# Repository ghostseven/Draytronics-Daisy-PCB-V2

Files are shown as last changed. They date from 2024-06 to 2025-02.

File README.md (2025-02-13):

# Draytronics-Daisy-PCB-V2

daisy  

An open source macro pad with a rotary encoder and OLED panel, this is an alternative version to the original through hole Daisy kit. More info / PCB designs available at [draytronics.co.uk/daisyV2](https://www.draytronics.co.uk/daisyv2/)

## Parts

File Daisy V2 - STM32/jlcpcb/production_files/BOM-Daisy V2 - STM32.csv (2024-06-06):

Comment | Designator | Footprint | LCSC
SN74LV1T34DBV | U5 | SOT-23-5 | C100024
5.1k | R1,R2,R3,R4,R5,R6 | R_0402_1005Metric | C105872
500mA | F1 | Fuse_1206_3216Metric | C135341
10uF | C2 | C_0603_1608Metric | C19702
PRTR5V0U2X | U2 | SOT-143 | C2827688
SW_SPST | BOOT1,RST1 | SW_SPST_TL3342 | C2886897
USB_C_Receptacle_USB2.0 | J1 | USB_C_Receptacle_HRO_TYPE-C-31-M-12 | C2988369
100nF | C1,C3,C4,C5,C6,C7,C8 | C_0402_1005Metric | C307331
1uF | C10,C9 | C_0402_1005Metric | C52923
XC6206PxxxMR-Regulator_Linear | U3 | SOT-23 | C5446
D_Small | D1,D2,D3,D4,D5,D6,D7,D8,D9 | D_SOD-123 | C81598
STM32F072CBT6 | U1 | LQFP-48_7x7mm_P0.5mm | C81720
MX_SW_solder | MX4 | SW_MX_1u
MX_SW_solder | MX8 | SW_MX_1u
MX_SW_solder | MX7 | SW_MX_1u
MX_SW_solder | MX3 | SW_MX_1u
MX_SW_solder | MX6 | SW_MX_1u
MX_SW_solder | MX1 | SW_MX_1u
MX_SW_solder | MX2 | SW_MX_1u
MX_SW_solder | MX5 | SW_MX_1u

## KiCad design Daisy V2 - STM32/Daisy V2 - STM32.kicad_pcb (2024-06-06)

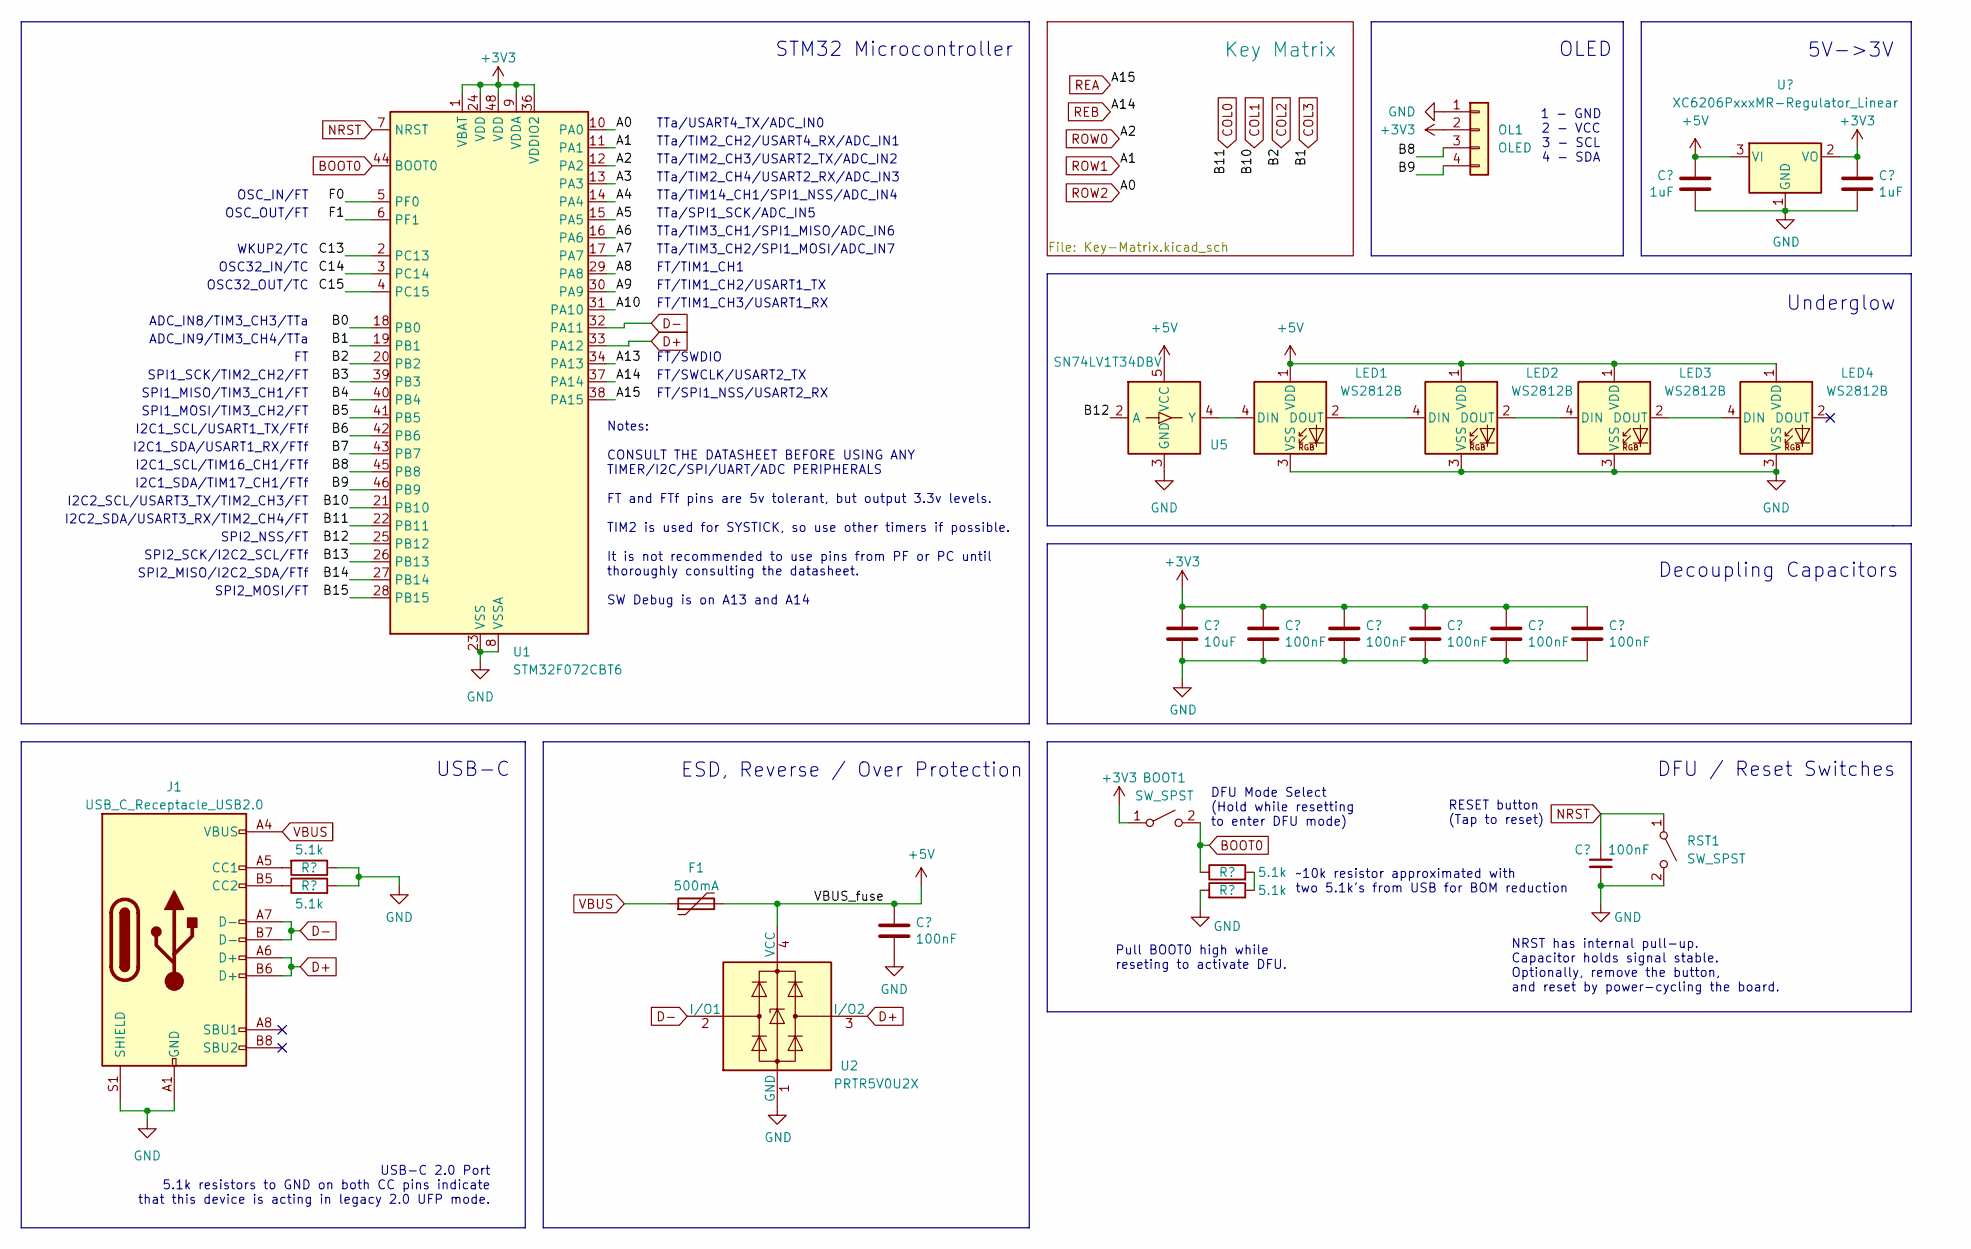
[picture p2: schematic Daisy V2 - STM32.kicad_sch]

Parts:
BOOT1: SW_SPST; SW_SPST_TL3342; LCSC Part # C2886897
C1, C3, C4, C5, C6, C7, C8: 100nF; C_0402_1005Metric; LCSC Part # C307331
C2: 10uF; C_0603_1608Metric; LCSC Part # C19702
C9, C10: 1uF; C_0402_1005Metric; LCSC Part # C52923
F1: 500mA; Fuse_1206_3216Metric; LCSC Part # C135341
J1: USB_C_Receptacle_USB2.0; USB_C_Receptacle_HRO_TYPE-C-31-M-12; JlcRotOffset 180
LED1, LED2, LED3, LED4: WS2812B; LED_WS2812B_PLCC4_5.0x5.0mm_P3.2mm; LCSC Part # C2843785
OL1: OLED; SSD1306-0.91-OLED-4pin-128x32
R1, R2, R3, R4: 5.1k; R_0402_1005Metric; LCSC Part # C105872
RST1: SW_SPST; SW_SPST_TL3342; LCSC Part # C2886897
U1: STM32F072CBT6; LQFP-48_7x7mm_P0.5mm; JlcRotOffset 90
U2: PRTR5V0U2X; SOT-143; LCSC Part # C2827688
U3: XC6206PxxxMR-Regulator_Linear; SOT-23; LCSC Part # C5446
U5: SN74LV1T34DBV; SOT-23-5; MPN SN74LV1T34DBVR; LCSC Part # C100024

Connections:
+3V3: BOOT1.1 (A), C2.1, C3.1, C4.1, C5.1, C6.1, C7.1, C10.1, OL1.2, U1.1 (VBAT), U1.9 (VDDA), U1.24 (VDD), U1.36 (VDDIO2), U1.48 (VDD), U3.2 (VO); also elsewhere on the board
+5V: C8.1, C9.1, F1.2, LED1.1 (VDD), LED2.1 (VDD), LED3.1 (VDD), LED4.1 (VDD), U2.4 (VCC), U3.3 (VI), U5.5 (VCC)
/A3: U1.13 (PA3)
/A4: U1.14 (PA4)
/A5: U1.15 (PA5)
/A6: U1.16 (PA6)
/A7: U1.17 (PA7)
/A8: U1.29 (PA8)
/A9: U1.30 (PA9)
/A10: U1.31 (PA10)
/A13: U1.34 (PA13)
/B0: U1.18 (PB0)
/B3: U1.39 (PB3)
/B4: U1.40 (PB4)
/B5: U1.41 (PB5)
/B6: U1.42 (PB6)
/B7: U1.43 (PB7)
/B8: OL1.3, U1.45 (PB8)
/B9: OL1.4, U1.46 (PB9)
/B12: U1.25 (PB12), U5.2 (A)
/B13: U1.26 (PB13)
/B14: U1.27 (PB14)
/B15: U1.28 (PB15)
/C13: U1.2 (PC13)
/C14: U1.3 (PC14)
/C15: U1.4 (PC15)
/F0: U1.5 (PF0)
/F1: U1.6 (PF1)
BOOT0: BOOT1.2 (B), R3.1, U1.44 (BOOT0)
COL0: U1.22 (PB11); also elsewhere on the board
COL1: U1.21 (PB10); also elsewhere on the board
COL2: U1.20 (PB2); also elsewhere on the board
COL3: U1.19 (PB1); also elsewhere on the board
D+: J1.A6 (D+), J1.B6 (D+), U1.33 (PA12), U2.3 (I/O2)
D-: J1.A7 (D-), J1.B7 (D-), U1.32 (PA11), U2.2 (I/O1)
GND: C1.2, C2.2, C3.2, C4.2, C5.2, C6.2, C7.2, C8.2, C9.2, C10.2, J1.A1 (GND), J1.A12 (GND), J1.B1 (GND), J1.B12 (GND), J1.S1 (SHIELD), LED1.3 (VSS), LED2.3 (VSS), LED3.3 (VSS), LED4.3 (VSS), OL1.1, R1.1, R2.2, R4.2, RST1.2 (B), U1.8 (VSSA), U1.23 (VSS), U1.35 (VSS), U1.47 (VSS), U2.1 (GND), U3.1 (GND), U5.3 (GND); also elsewhere on the board
NRST: C1.1, RST1.1 (A), U1.7 (NRST)
unnamed: J1.A5 (CC1), R1.2
unnamed: J1.B5 (CC2), R2.1
unnamed: LED1.4 (DIN), U5.4 (Y)
unnamed: LED1.2 (DOUT), LED2.4 (DIN)
unnamed: LED2.2 (DOUT), LED3.4 (DIN)
unnamed: LED3.2 (DOUT), LED4.4 (DIN)
unnamed: R3.2, R4.1
REA: U1.38 (PA15); also elsewhere on the board
REB: U1.37 (PA14); also elsewhere on the board
ROW0: U1.12 (PA2); also elsewhere on the board
ROW1: U1.11 (PA1); also elsewhere on the board
ROW2: U1.10 (PA0); also elsewhere on the board
VBUS: F1.1, J1.A4 (VBUS), J1.A9 (VBUS), J1.B4 (VBUS), J1.B9 (VBUS)

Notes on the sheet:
SPI1_SCK/TIM2_CH2/FT
STM32 Microcontroller
FT/TIM1_CH1
FT/TIM1_CH3/USART1_RX
SPI2_NSS/FT
Notes: CONSULT THE DATASHEET BEFORE USING ANY TIMER/I2C/SPI/UART/ADC PERIPHERALS FT and FTf pins are 5v tolerant, but output 3.3v levels. TIM2 is used for SYSTICK, so use other timers if possible. It is not recommended to use pins from PF or PC until thoroughly consulting the datasheet. SW Debug is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
TTa/TIM2_CH4/USART2_RX/ADC_IN3
NRST has internal pull-up. Capacitor holds signal stable. Optionally, remove the button, and reset by power-cycling the board.
FT/SWDIO
Decoupling Capacitors
SPI1_MOSI/TIM3_CH2/FT
ADC_IN9/TIM3_CH4/TTa
I2C2_SCL/USART3_TX/TIM2_CH3/FT
DFU / Reset Switches
SPI2_MISO/I2C2_SDA/FTf
FT/SWCLK/USART2_TX
I2C1_SCL/TIM16_CH1/FTf
Underglow
~10k resistor approximated with two 5.1k's from USB for BOM reduction
TTa/TIM2_CH2/USART4_RX/ADC_IN1
USB-C 2.0 Port 5.1k resistors to GND on both CC pins indicate that this device is acting in legacy 2.0 UFP mode.
TTa/TIM2_CH3/USART2_TX/ADC_IN2
OSC_IN/FT
DFU Mode Select (Hold while resetting to enter DFU mode)
WKUP2/TC
I2C2_SDA/USART3_RX/TIM2_CH4/FT
ADC_IN8/TIM3_CH3/TTa
1 - GND 2 - VCC 3 - SCL 4 - SDA
RESET button (Tap to reset)
Pull BOOT0 high while reseting to activate DFU.
I2C1_SDA/TIM17_CH1/FTf
USB-C
TTa/SPI1_SCK/ADC_IN5
TTa/TIM3_CH1/SPI1_MISO/ADC_IN6
TTa/TIM3_CH2/SPI1_MOSI/ADC_IN7
OSC32_OUT/TC
FT/SPI1_NSS/USART2_RX
SPI1_MISO/TIM3_CH1/FT
OSC32_IN/TC
OLED

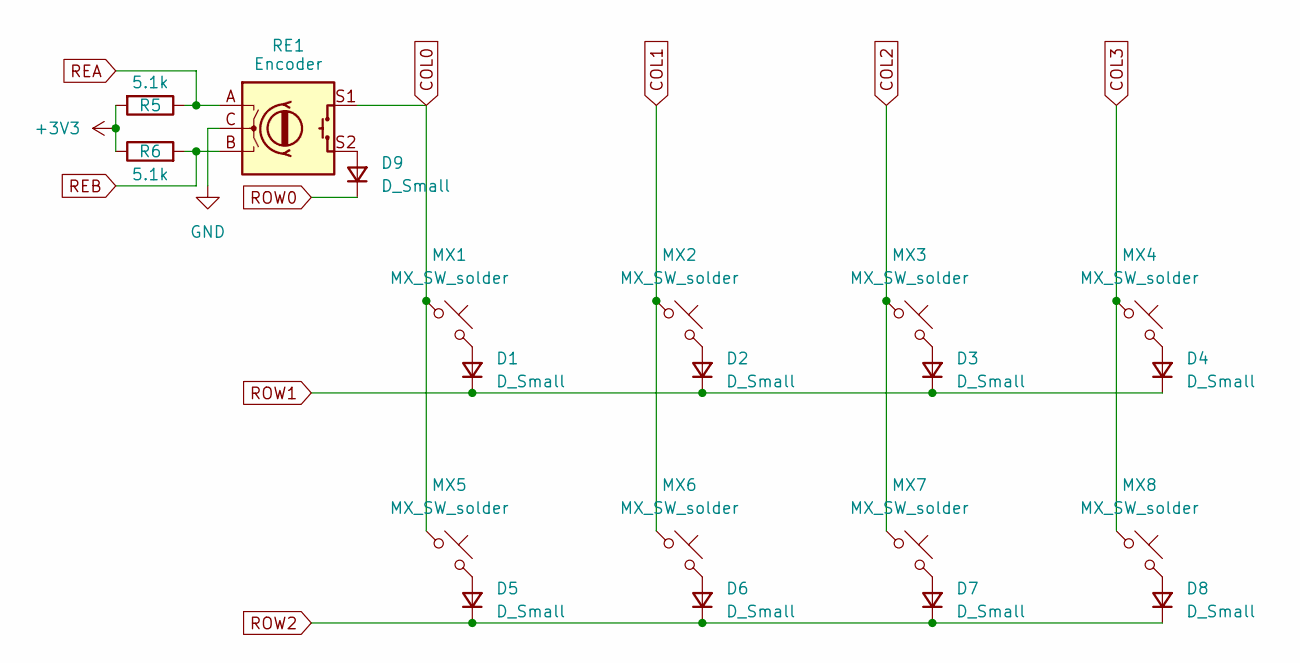
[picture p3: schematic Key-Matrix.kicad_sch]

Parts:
D1, D2, D3, D4, D5, D6, D7, D8, D9: D_Small; D_SOD-123; LCSC Part # C81598
MX1, MX2, MX3, MX4, MX5, MX6, MX7, MX8: MX_SW_solder; SW_MX_1u
R5, R6: 5.1k; R_0402_1005Metric; LCSC Part # C105872
RE1: Encoder; RotaryEncoder_Alps_EC11E-Switch_Vertical_H20mm

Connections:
+3V3: R5.2, R6.1; also elsewhere on the board
COL0: MX1.1, MX5.1, RE1.S1; also elsewhere on the board
COL1: MX2.1, MX6.1; also elsewhere on the board
COL2: MX3.1, MX7.1; also elsewhere on the board
COL3: MX4.1, MX8.1; also elsewhere on the board
GND: RE1.C; also elsewhere on the board
unnamed: D1.2 (A), MX1.2
unnamed: D2.2 (A), MX2.2
unnamed: D3.2 (A), MX3.2
unnamed: D4.2 (A), MX4.2
unnamed: D5.2 (A), MX5.2
unnamed: D6.2 (A), MX6.2
unnamed: D7.2 (A), MX7.2
unnamed: D8.2 (A), MX8.2
unnamed: D9.2 (A), RE1.S2
REA: R5.1, RE1.A; also elsewhere on the board
REB: R6.2, RE1.B; also elsewhere on the board
ROW0: D9.1 (K); also elsewhere on the board
ROW1: D1.1 (K), D2.1 (K), D3.1 (K), D4.1 (K); also elsewhere on the board
ROW2: D5.1 (K), D6.1 (K), D7.1 (K), D8.1 (K); also elsewhere on the board

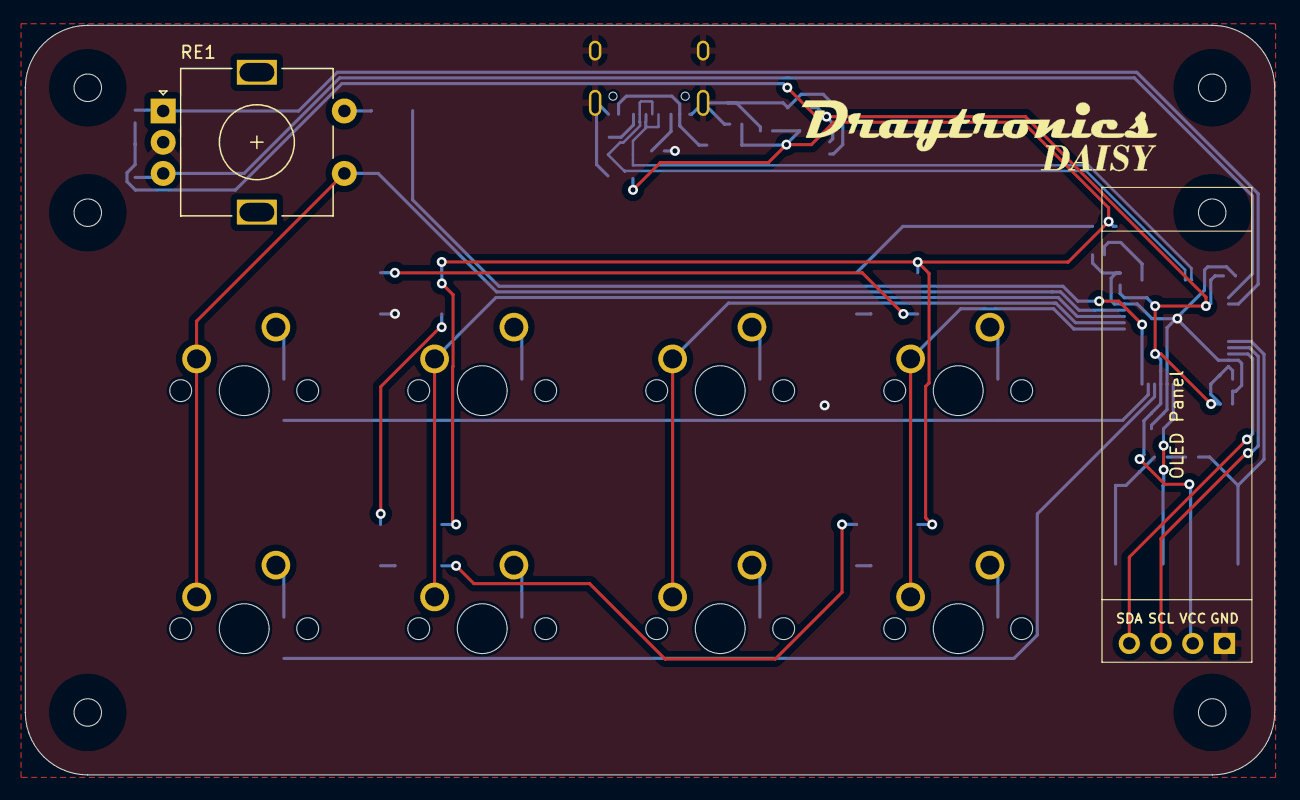
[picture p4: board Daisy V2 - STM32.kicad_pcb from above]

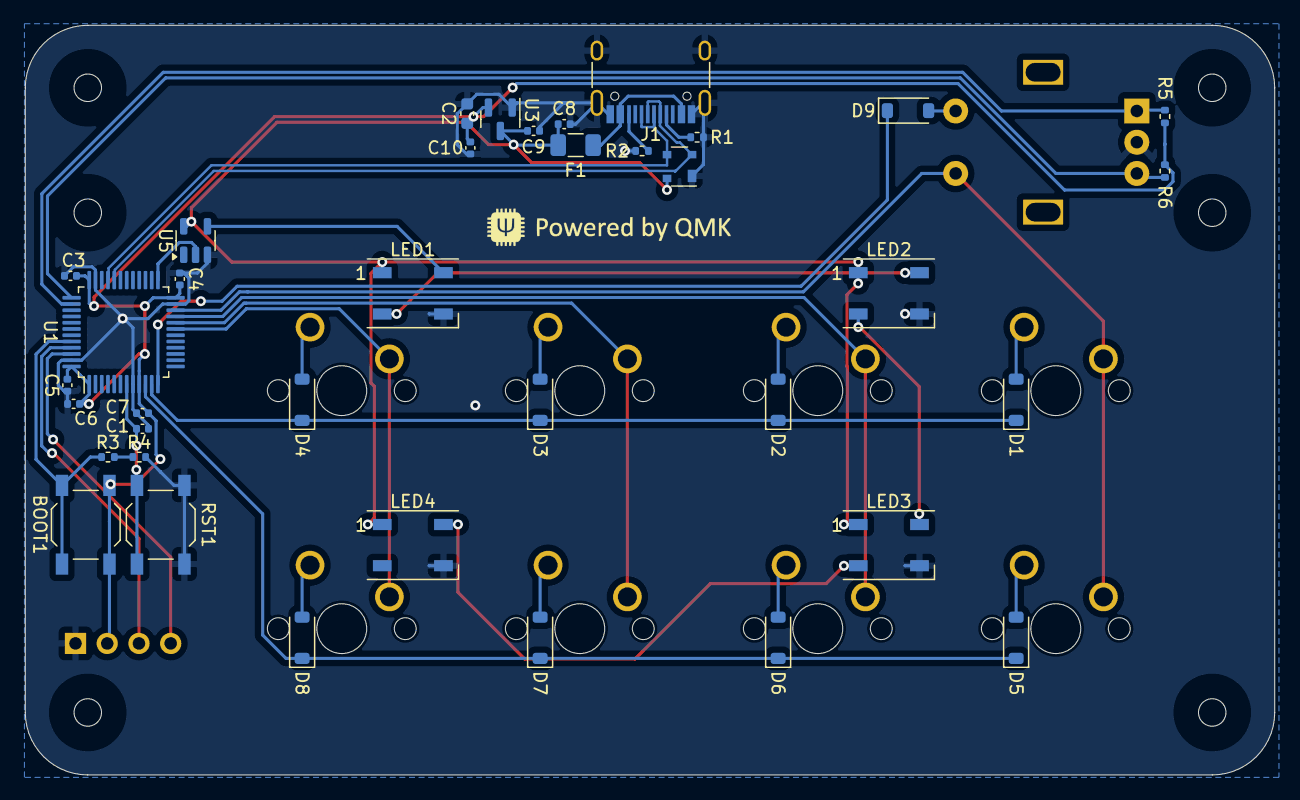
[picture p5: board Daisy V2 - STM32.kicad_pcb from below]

Board: 2 copper layers, 100.0 x 60.0 mm, 47 parts (37 on the bottom side), 36 nets.
